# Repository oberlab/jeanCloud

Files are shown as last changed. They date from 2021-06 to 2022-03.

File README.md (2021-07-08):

<p align="center">
<h1 align="center">jeanCloud</h1>
<h3 align="center">Your personal cloud (alarm) clock</h3>
</p>

<p align="center">
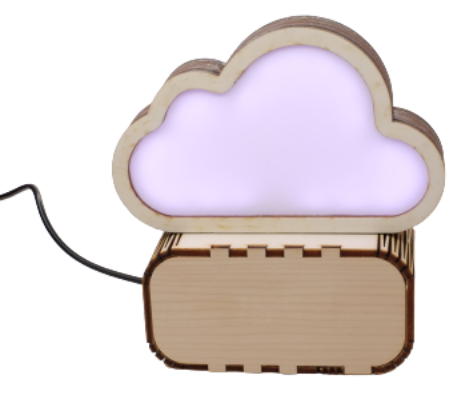
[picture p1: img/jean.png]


</p>
<br>
<br>

### How to set up your JeanCloud in your home network

1. Connect your JeanCloud to power
2. Wait until the JeanCloud WiFi appears
3. Connect to the JeanCloud WiFi and enter 192.168.4.1 into your web browser (NO GOOGLE SEARCH)
4. You should see a web interface in which you can enter the name and password of your home WiFi
5. After you press "save" the JeanCloud WiFi should disappear and your JeanCloud connects to your home WiFi
6. You can access the web interface of your JeanCloud by entering its IP address into your web browser (with a device which is in the SAME network). You can identify the IP address of your JeanCloud either by using any network analysis tool (like the [app fing](https://www.fing.com/products/fing-app)) or looking into your router web interface. Check for connected (generic) devices and identify your JeanCloud (sometimes the device is named "espressif")

### Jean Cloud mit dem Heimnetzwerk verbinden

1. Versorge deinen JeanCloud mit Strom
2. Warte bis das JeanCloud WLan erscheint
3. Verbinde dich mit dem JeanCloud WLan und gebe 192.168.4.1 in der Adresszeile deines Webbrowsers ein (KEINE GOOGLE SUCHE)
4. Du solltest jetzt ein Webinterface sehen in dem du den Namen und das Passwort deines Heimnetzwerks eingeben kannst
5. Wenn du jetzt "Speichern" drückst, sollte das JeanCloud WLan verschwinden und dein JeanCloud sich mit deinem Heimnetzwerk verbinden
6. Du kannst jetzt das Webinterface zur Steuerung des Lichts etc. aufrufen indem du die IP Adresse deines JeanClouds in der Adresszeile deines Webbrowsers eingibst. Du kannst die IP Adresse deines JeanClouds entweder durch ein Netzwerkanalyse Tool wie z.B. die [App fing](https://www.fing.com/products/fing-app) oder über das Webinteface von deinem Heimrouter (schau unter verbundene Geräte) herausfinden.

### Electronic connections

**Display:** CLK to pin 18, DIO to pin 5, 5V to 3V3, GND to GND
**LED-Strip:** Data to pin 14, 5V to 5V or Vin, GND to GND
**Buzzer:** one leg to pin 32, one leg to GND (use the one of the display)

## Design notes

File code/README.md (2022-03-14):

## Pin Usage
**Display:** CLK to pin 18, DIO to pin 5
**LED-Strip:** pin 14
**Buzzer:** pin 32

## Inspiration:

- [show text in with the 4-digit display](https://www.rahner-edu.de/mikrocontroller/seeeduino-nano/4-digit-display/)
- [different WS2811 LED pattern (FastLED)](https://www.tweaking4all.com/hardware/arduino/arduino-all-ledstrip-effects-in-one/)

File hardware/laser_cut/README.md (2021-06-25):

## Files for lasercutting

## How to create your own cloud design
I suggest to use [Inkscape](https://inkscape.org/) to create your own cloud design. Follow these steps:

(Use an area of about 140 x 80 mm for your drawing)

1. Draw circles or ellipses. The outer shape will form the outline of your cloud
<p align="center">
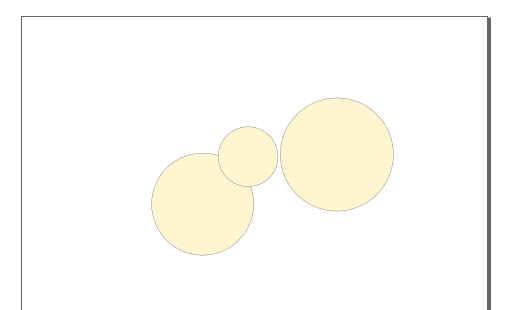
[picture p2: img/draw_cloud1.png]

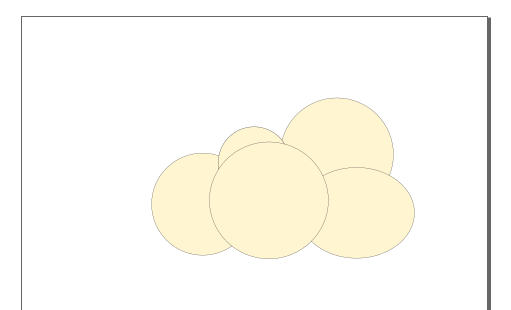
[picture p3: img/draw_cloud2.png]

</p>

2. Select all circles and unionize them to one shape (Path > Union or press ctrl and +)

<p align="center">
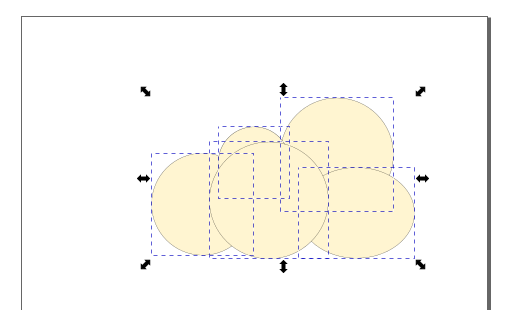
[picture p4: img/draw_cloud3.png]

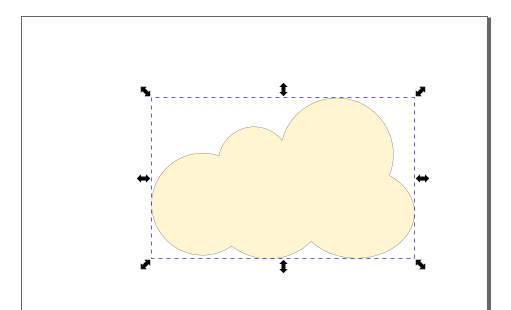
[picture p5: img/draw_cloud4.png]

</p>

3. Duplicate the shape (ctrl + D or right click on the shape) two times. Put one to the side for later. Create an dynamic offset with the other duplicate (Path > Dynamic offset or press ctrl + J). Pull the dynamic offset in any direction.

<p align="center">
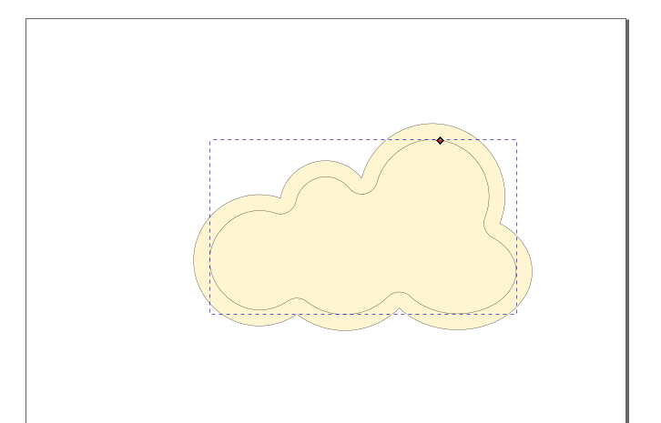
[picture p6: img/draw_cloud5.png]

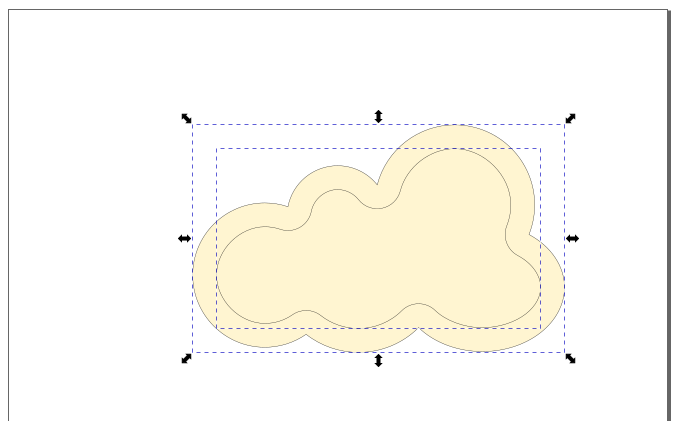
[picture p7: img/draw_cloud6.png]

</p>

4. First duplicate the offset shape (ctrl + D or right click on the shape) and put it to the side  Now subtract (Path > Difference or ctrl + -) the new smaller shape from the previous one. Again create a duplicate (ctrl + D or right click on the shape) and put it to the side for later.

<p align="center">
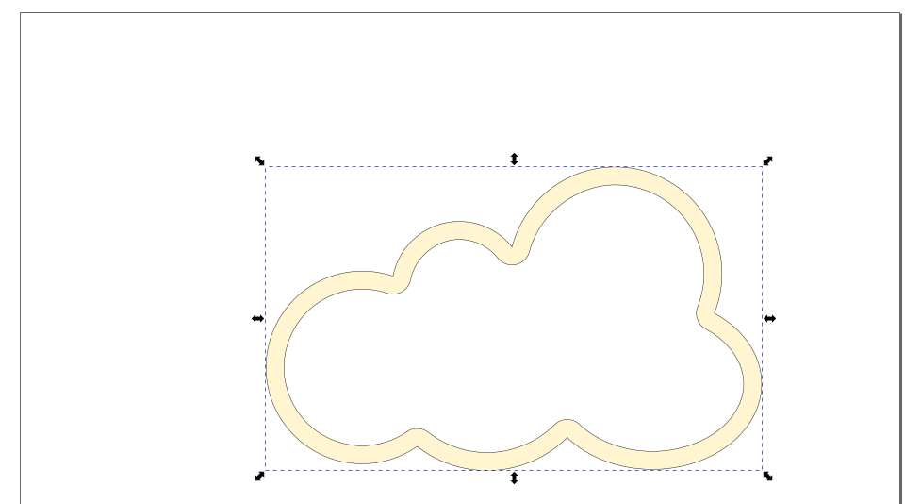
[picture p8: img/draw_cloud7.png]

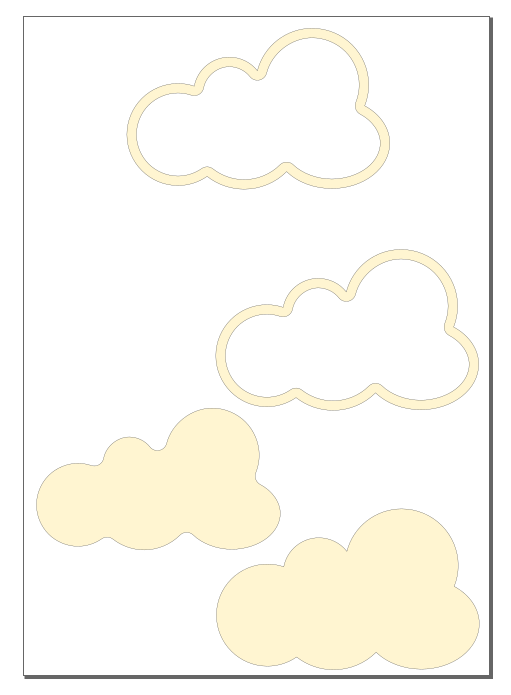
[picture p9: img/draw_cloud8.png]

</p>

5. Create a rectangle with 70 mm width and 25 mm height and place it below the cloud. Unionize both shapes (Path > Union or press ctrl and +). This is the part you will insert into the box later.

<p align="center">
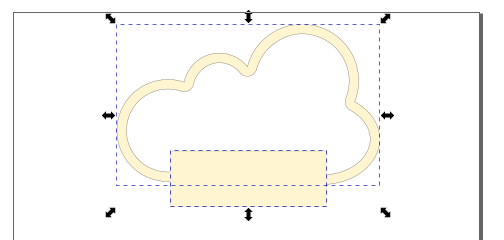
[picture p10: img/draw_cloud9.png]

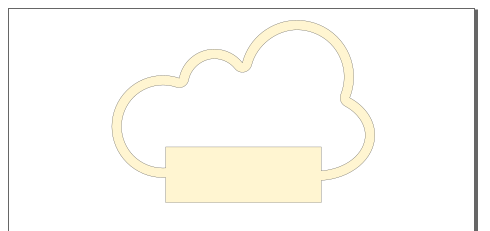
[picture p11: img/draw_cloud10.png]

</p>

6. Create a a duplicate of the offset shape (from step 4) and put it into the cloud shape with the box. Subtract it from the shape (Path > Difference or ctrl + -) to get a nice inner shape again (there are better ways to do this but this one seemed easier for me).

<p align="center">
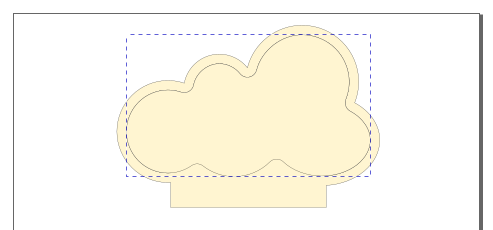
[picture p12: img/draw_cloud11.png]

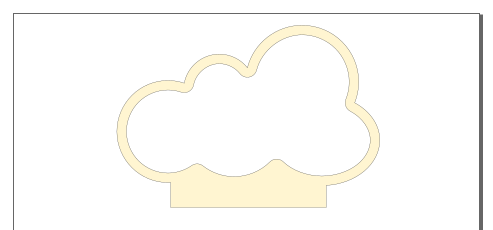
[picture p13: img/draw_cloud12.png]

</p>

7. Now we need to create a channel for the LED cables. Create a small rectangle with 15 mm width (height does not matter) and place it in the middle of the bottom part and subtract it from the shape (Path > Difference or ctrl + -).

<p align="center">
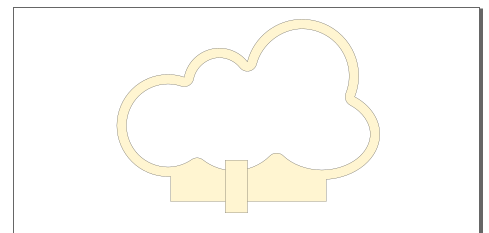
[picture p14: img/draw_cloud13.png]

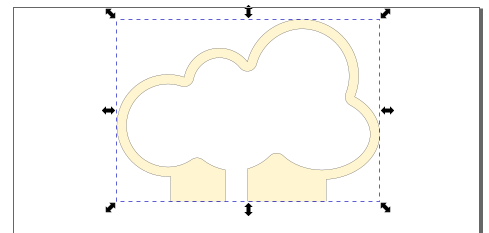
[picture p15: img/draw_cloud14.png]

</p>

8. Quick check. You should now have 4 shapes on your inkscape document: 1. Outline with connector and cable channel (from step 7), 2. Outline (from step 4), 3. Offset cloud shape (from step 4) and 4. Cloud shape (from step 2).

<p align="center">
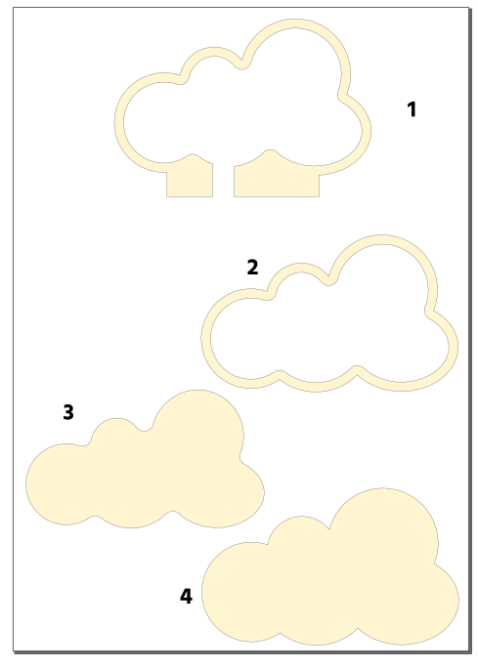
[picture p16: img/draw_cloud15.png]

</p>

9. Now let's create the parts which hold the veneer/white sheet for the light. Duplicate the outline shape created in step 4 (number in the previous picture) and drag it to the side. Lay the cloud shape over the duplicated outline.

<p align="center">
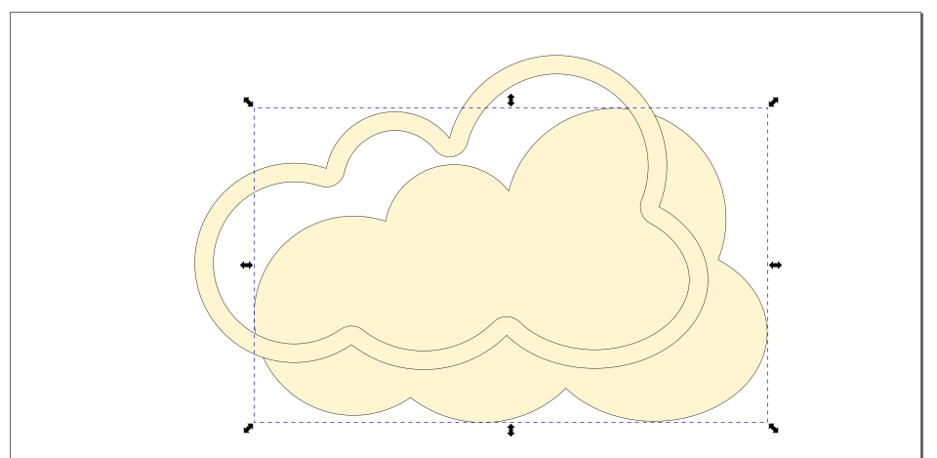
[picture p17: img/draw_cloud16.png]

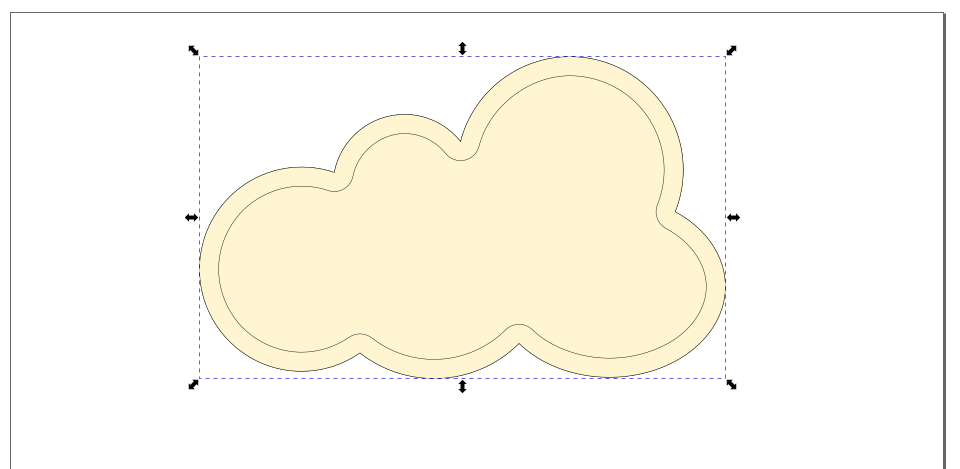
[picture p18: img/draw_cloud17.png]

</p>

10. Select the cloud shape and do a dynamic offset again (Path > Dynamic offset or press ctrl + J) and pull it in the middle of the Cloud Outline. You might have to zoom in to get it right.

<p align="center">
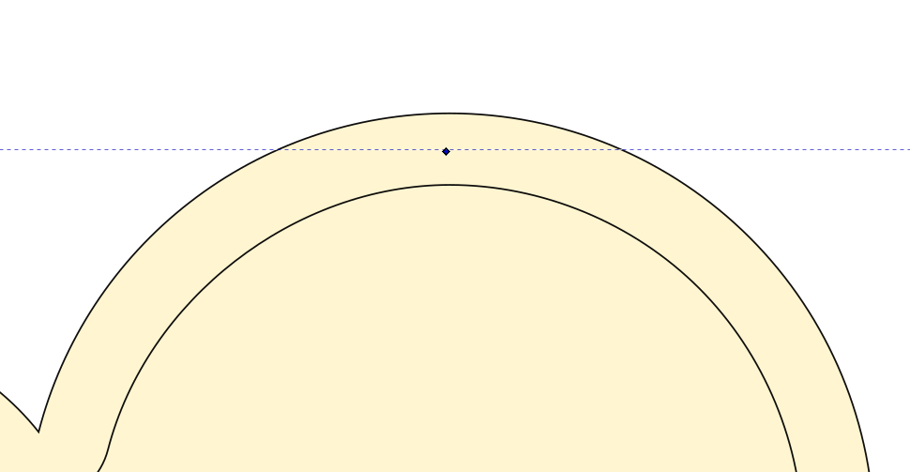
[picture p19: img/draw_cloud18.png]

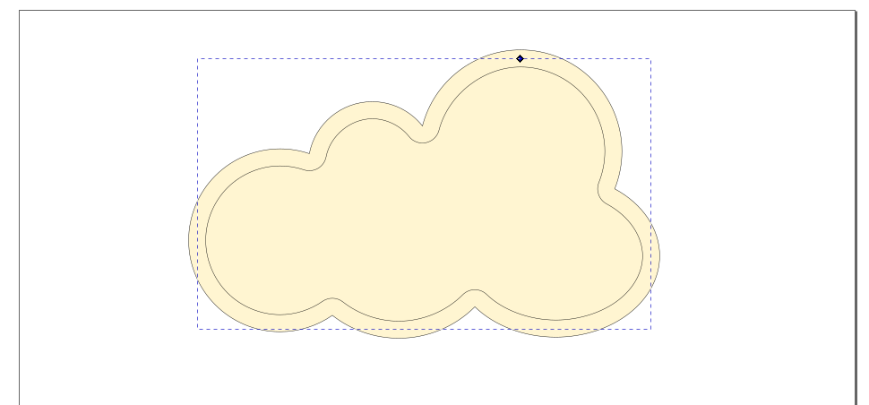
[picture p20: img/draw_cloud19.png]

</p>

11. Create a duplicate of the new shape and put it to the side. Now select both overlaying shapes and create an intersection (Path > Intersection or ctrl + *)

<p align="center">
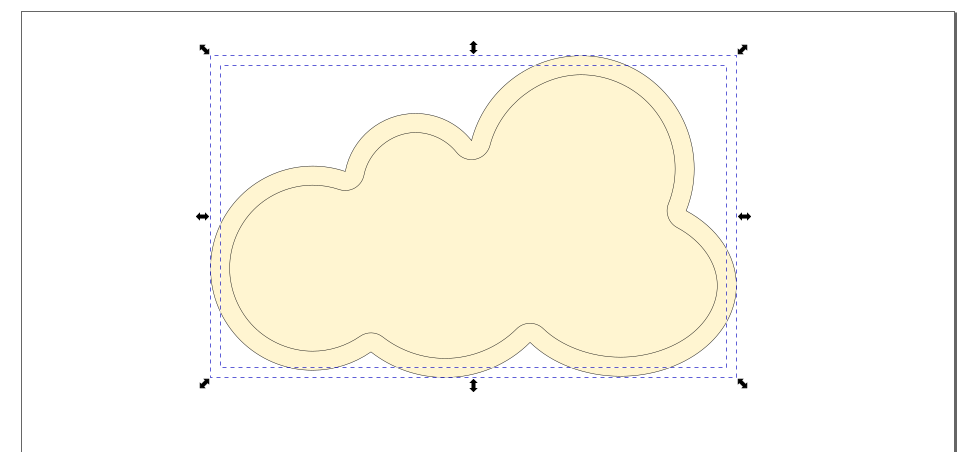
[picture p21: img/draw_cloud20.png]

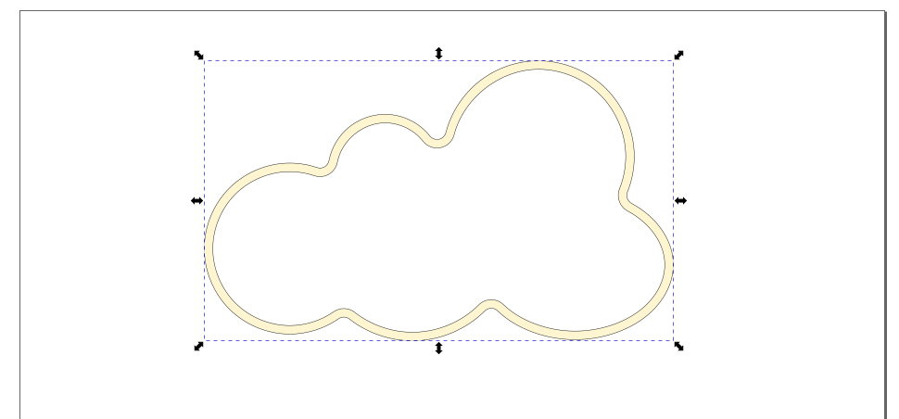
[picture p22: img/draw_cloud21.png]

</p>

12. For the last part create a duplicate of the cloud outline again and a duplicate from the smaller cloud shape we created in step 10/11. Drag them both to the side and lay them over each other. It is important that the bigger shape is below the smaller shape. You can change the order in the toolbar. They should be also perfectly centred to each other. You can do this by using the Align and Distribute tool (Object > Align and Distribute)  Finally subtract the shapes (Path > Difference or ctrl + -).

<p align="center">
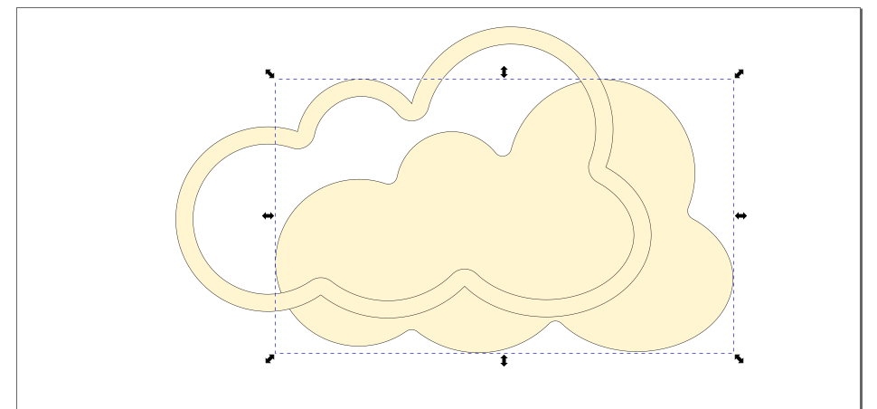
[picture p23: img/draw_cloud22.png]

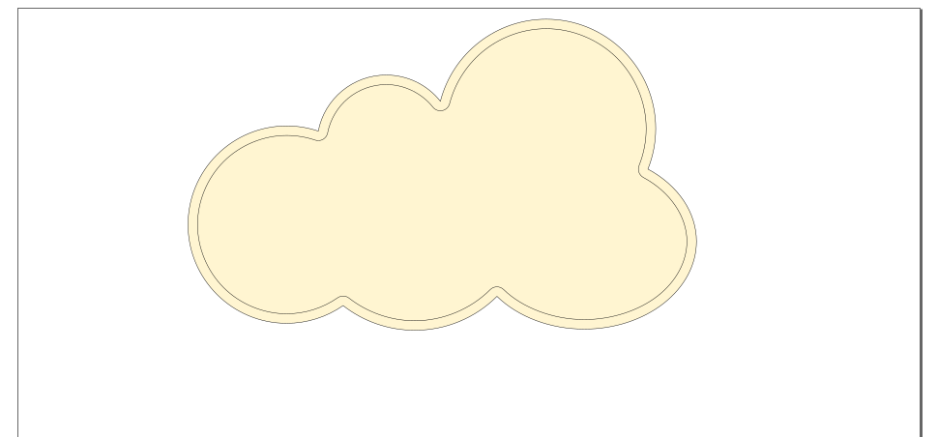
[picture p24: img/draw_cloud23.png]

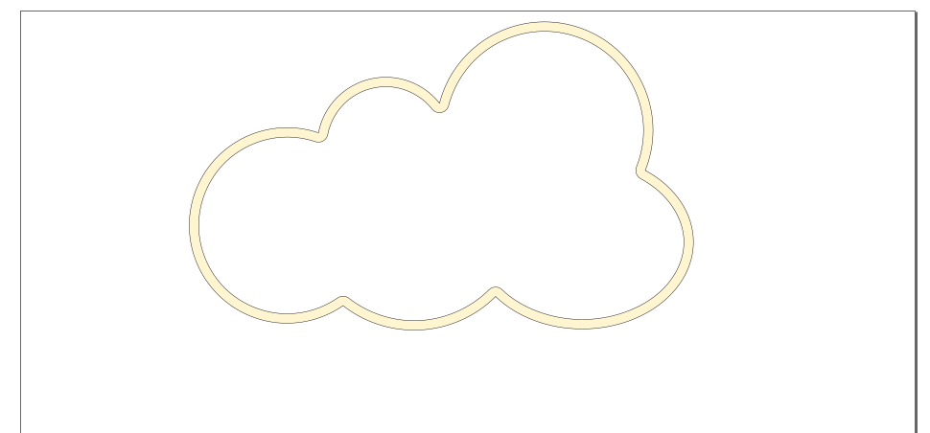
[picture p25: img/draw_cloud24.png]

</p>

13. Final check! Now you should have 5 shapes! 1. The outer outline (from step 12), the cloud outline, 3. the inner outline (from step 11), 4. outline with connector and cable channel (from step 7) and 5. smaller cloud shape from step 11.

<p align="center">

</p>

### Box generators
- [MakerCase](https://de.makercase.com/)
- [boxes.py](https://www.festi.info/boxes.py/)

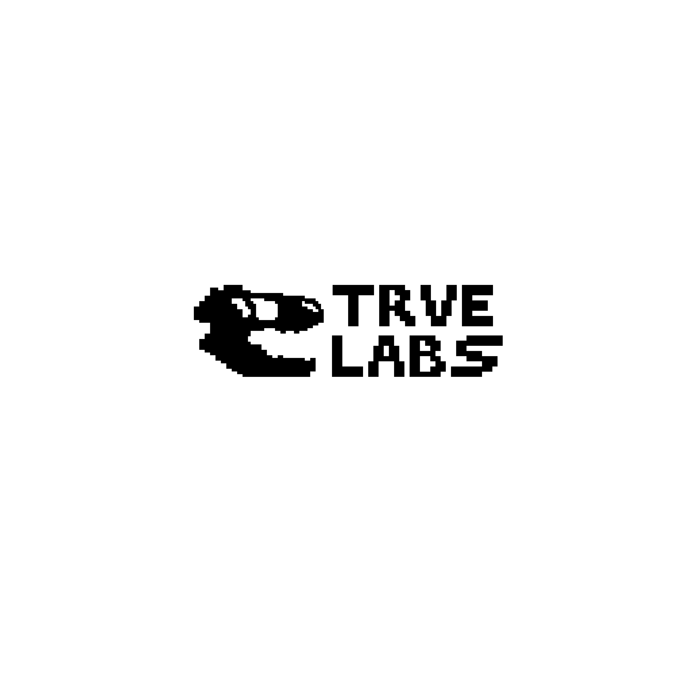
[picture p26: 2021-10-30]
hardware/pcb/regular/.svg2shenzhen-cache/images/F.Mask_g844.png

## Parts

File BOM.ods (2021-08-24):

Quantity | Description | Where to buy? | Example | Aprox. Costs per unit | Aprox. Costs (per JeanCloud) | Total est. costs
1 | ESP32 Dev Kit | anywhere | Aliexpress (https://de.aliexpress.com/item/32807887667.html) | 5.00 € | 2.00 € | 23.50 €
1 | active Buzzer | anywhere | digikey (https://www.digikey.de/product-detail/de/tdk-corporation/PS1240P02BT/445-2525-1-ND/935930) | 0.50 € | 0.50 €
1 | 4-digits TM1637 Display | anywhere | Aliexpress (https://de.aliexpress.com/item/32838969764.html) | 2.50 € | 2.50 €
1 | WS2812B LED Strip (NeoPixel) | anywhere | Aliexpress (https://de.aliexpress.com/item/32832420003.html) | 2.00 € | 2.00 €
1 | connector cables | anywhere | Aliexpress (https://de.aliexpress.com/item/4000203371860.html) | 2.00 € | 2.00 €
2 | PCB Push Buttons | anywhere | Aliexpress (https://de.aliexpress.com/item/4000113193157.html) | 0.50 € | 1.00 €
1 | MicroUSB Adapter (optional) | anywhere | Amazon (https://www.amazon.de/gp/product/B0754MNQPN?psc=1) | 7.00 € | 7.00 €
1 | Wood housing | Laser cut | - | 5.00 € | 5.00 €
1 | CloudPush Adapter | 3D-print | - | 1.00 € | 1.00 €
1 | DisplaySpacer | 3D-print | - | 0.50 € | 0.50 €

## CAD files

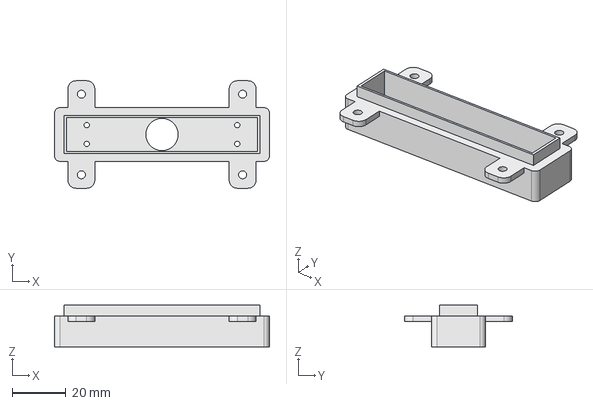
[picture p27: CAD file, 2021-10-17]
hardware/3D_print/CloudPush/CloudPush.FCStd
80.0 x 40.0 x 15.5 mm

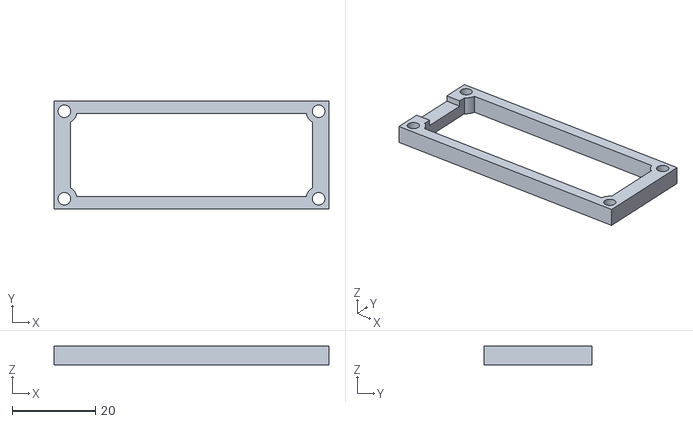
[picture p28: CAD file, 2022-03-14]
hardware/3D_print/DisplaySpace/DisplaySpacer-Body.obj
66.0 x 26.0 x 4.50

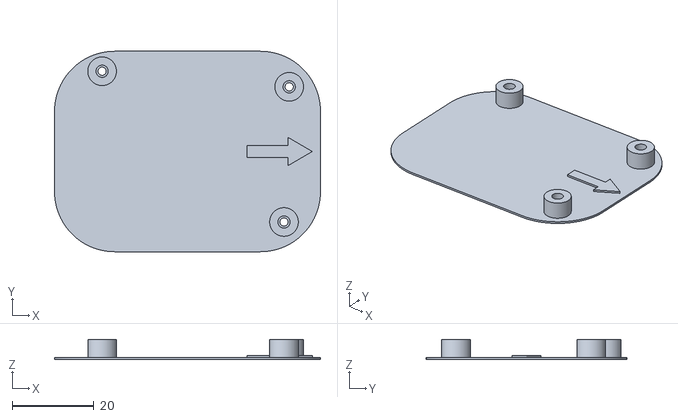
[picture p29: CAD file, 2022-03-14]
hardware/3D_print/PCBholder/PCBholder-Body.obj
65.0 x 49.0 x 5.00

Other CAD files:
hardware/3D_print/CloudPush/CloudPush-Body.obj
hardware/3D_print/DisplaySpace/DisplaySpacer.FCStd
hardware/3D_print/PCBholder/PCBholder.FCStd

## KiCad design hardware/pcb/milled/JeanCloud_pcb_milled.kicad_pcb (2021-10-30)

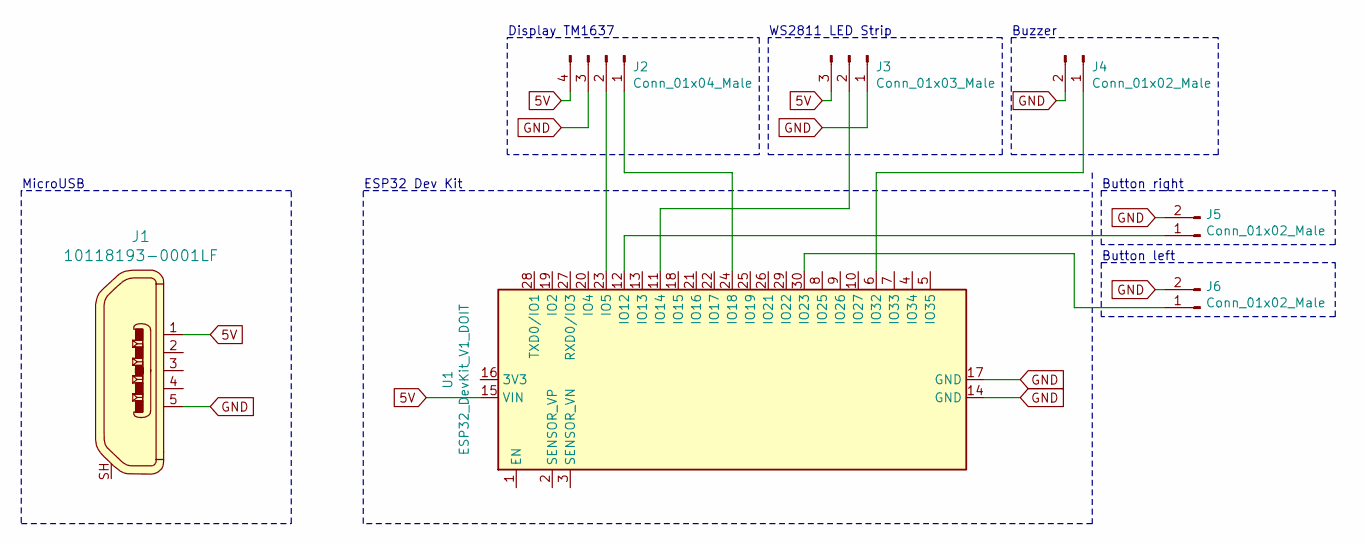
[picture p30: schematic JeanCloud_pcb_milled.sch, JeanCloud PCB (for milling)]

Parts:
J1: 10118193-0001LF; USB_Micro_B_Female_10118193-0001LF; MPN 10118193-0001LF; Digi-Key_PN 609-4616-1-ND
J2: Conn_01x04_Male; PinHeader_1x04_P2.54mm_Vertical
J3: Conn_01x03_Male; PinHeader_1x03_P2.54mm_Vertical
J4, J5, J6: Conn_01x02_Male; PinHeader_1x02_P2.54mm_Vertical
U1: ESP32_DevKit_V1_DOIT; esp32_devkit_v1_doit

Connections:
5V: J1.1, J2.4, J3.3, U1.15 (VIN)
GND: J1.5, J2.3, J3.1, J4.2, J5.2, J6.2, U1.14 (GND), U1.17 (GND)
unnamed: J2.1, U1.24 (IO18)
unnamed: J2.2, U1.23 (IO5)
unnamed: J3.2, U1.11 (IO14)
unnamed: J4.1, U1.6 (IO32)
unnamed: J5.1, U1.12 (IO12)
unnamed: J6.1, U1.30 (IO23)

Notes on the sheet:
Display TM1637
WS2811 LED Strip
Buzzer
Button right
Button left
ESP32 Dev Kit
MicroUSB

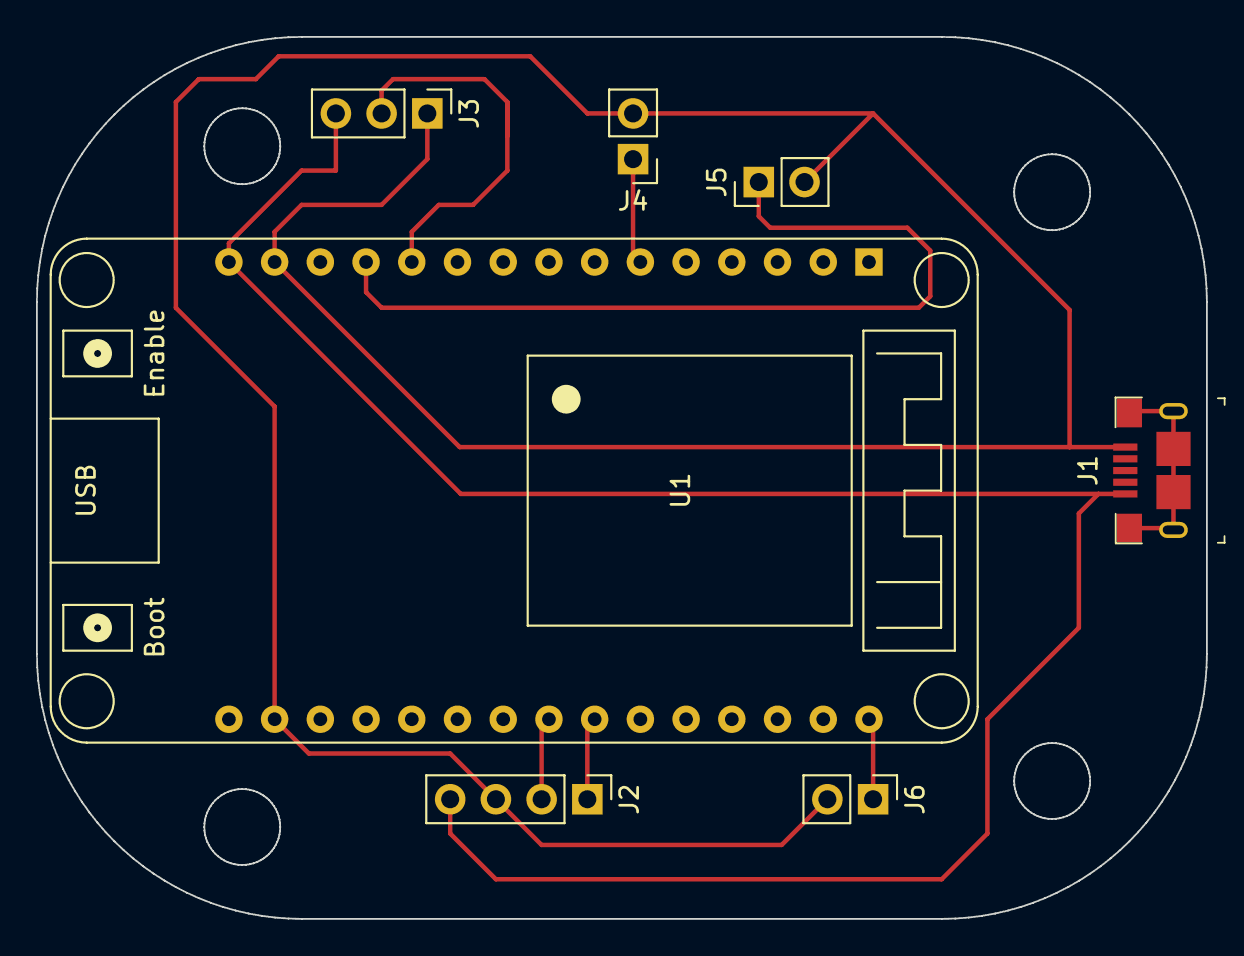
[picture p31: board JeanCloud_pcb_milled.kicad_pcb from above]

Board: 2 copper layers, 65.0 x 49.0 mm, 7 parts (0 on the bottom side), 8 nets.

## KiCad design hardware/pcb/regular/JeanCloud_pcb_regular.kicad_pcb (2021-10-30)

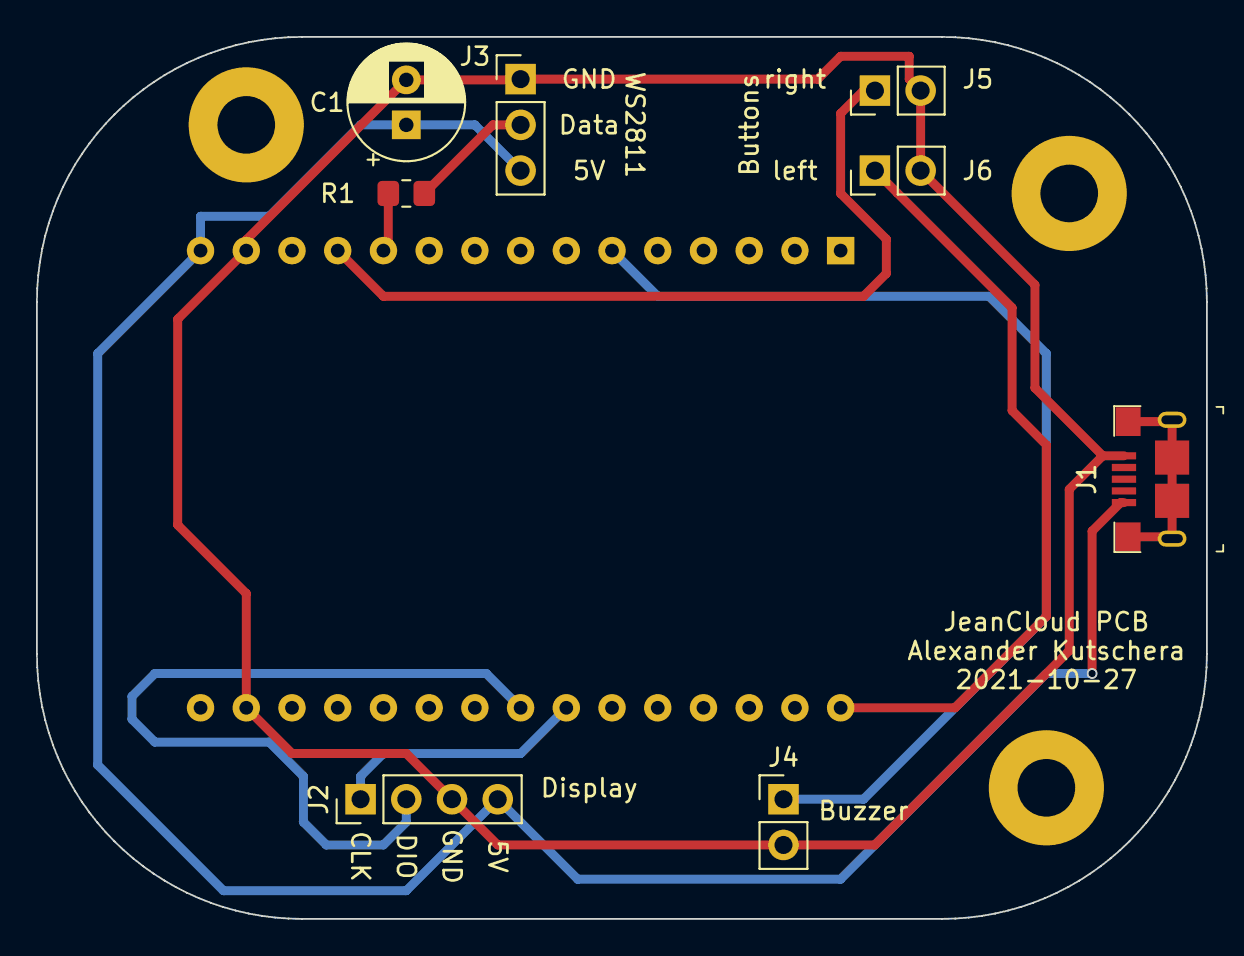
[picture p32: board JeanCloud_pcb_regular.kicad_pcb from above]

Board: 2 copper layers, 65.0 x 49.0 mm, 12 parts (0 on the bottom side), 9 nets.

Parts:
 : MountingHole_3.2mm_M3_Pad
 #2,  #3: MountingHole_3.2mm_M3_Pad
 #4: ESP32_DevKit_V1_DOIT; esp32_devkit_v1_doit
C1: CP; CP_Radial_D6.3mm_P2.50mm
J1: 10118193-0001LF; USB_Micro_B_Female_10118193-0001LF
J2: Conn_01x04_Male; PinHeader_1x04_P2.54mm_Vertical
J3: Conn_01x03_Male; PinHeader_1x03_P2.54mm_Vertical
J4, J5, J6: Conn_01x02_Male; PinHeader_1x02_P2.54mm_Vertical
R1: R; R_0805_2012Metric_Pad1.20x1.40mm_HandSolder

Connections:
5V: #4.15, C1.1, J1.1, J2.4, J3.3
GND: #4.14, #4.17, C1.2, J1.5, J2.3, J3.1, J4.2, J5.2, J6.2
unnamed: #4.24, J2.1
unnamed: #4.23, J2.2
unnamed: J3.2, R1.1
unnamed: #4.6, J4.1
unnamed: #4.12, J5.1
unnamed: #4.30, J6.1
unnamed: #4.11, R1.2

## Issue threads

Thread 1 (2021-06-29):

feature list v1

vektorious, 2021-06-29:
- [x] Webserver
- [x] get time (sync.
- [x] switch light on/off (Backend)
- [x] switch light on/off (Frontend)
- [x] set color (R, G, B)
- [x] Show Status (Intestity)
- [x] AP if no WiFi connection
- [x] set alarm time
- [x] switch alarm on and off

---
*optional*
- [ ] set alarm melody
- [ ] LED pattern/light modes

---
*super optional*
- [ ] connect to open weather map and show the weather

vektorious, 2021-07-09:
Closed because we are changing our project management

Closed 2021-07-09.

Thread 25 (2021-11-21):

winter/summer time switch

vektorious, 2021-11-21:
Switch between German winter and summer time is not working. Needs to be fixed.
Maybe check date at startup and adjust offset accordingly.

vektorious, 2022-03-11:
@konstantinullrich

Closed 2022-03-17.

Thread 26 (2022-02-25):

Add watchdog reset

vektorious, 2022-02-25:
https://iotespresso.com/create-custom-watchdog-timer-in-esp32/

vektorious, 2022-02-25:
https://iotespresso.com/create-custom-watchdog-timer-in-esp32/

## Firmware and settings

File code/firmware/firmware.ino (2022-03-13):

#include <AsyncTCP.h>
#include <ESPAsyncWebServer.h>
#include <ESPmDNS.h>
#include <FastLED.h>
#include <SPIFFS.h>
#include <TM1637Display.h>
#include <WiFi.h>
#include <time.h>
#include "./src/hardware/LightController.h"
#include "./src/network/MDNSController.h"
#include "./src/AlarmController.h"
#include "./src/PasswordController.h"
#include "./src/hardware/System.h"
#include "./src/Webserver.h"

char *name = "Konsti's JeanCloud";
char *hostname = "jeancloud";
char *passwort = "passwort123";

// Define the connections pins for display:
#define CLK 18
#define DIO 5

// Create display object:
TM1637Display display = TM1637Display(CLK, DIO);

// time settings
#define MY_NTP_SERVER "de.pool.ntp.org"  
#define MY_TZ "CET-1CEST,M3.5.0/02,M10.5.0/03" // https://github.com/nayarsystems/posix_tz_db/blob/master/zones.csv


MDNSController mdnsController = MDNSController(hostname, name);
LightController lightController = LightController();
AlarmController alarmController = AlarmController(&lightController);
Webserver webserver = Webserver(80, lightController, &alarmController, &display);
Webserver apWebserver = Webserver(80, lightController, &alarmController, &display);

bool isSetup = false;

struct Button
{
  uint8_t pin;
  uint32_t numberKeyPresses;
  bool pressed;
};

Button buttonRight = {12, 0, false};
Button buttonLeft = {33, 0, false};

void IRAM_ATTR buttonRightIRS()
{
  buttonRight.numberKeyPresses += 1;
  buttonRight.pressed = true;
}

void IRAM_ATTR buttonLeftIRS()
{
  buttonLeft.numberKeyPresses += 1;
  buttonLeft.pressed = true;
}

void setup()
{
  Serial.begin(115200);

  // setup display
  display.setBrightness(7); // Set the display brightness (0-7)
  display.clear();          // Clear the display

  System::initFS();

  PasswordController passwordController = PasswordController("/wifi.txt");

  pinMode(buttonRight.pin, INPUT_PULLUP);
  pinMode(buttonLeft.pin, INPUT_PULLUP);
  attachInterrupt(buttonRight.pin, buttonRightIRS, FALLING);
  attachInterrupt(buttonLeft.pin, buttonLeftIRS, FALLING);

  if (!passwordController.isExisting())
  {
    isSetup = true;
  }
  else
  {
    isSetup = !System::connectToWifi(&passwordController);
  }

  if (isSetup)
  {
    WiFi.disconnect();
    WiFi.mode(WIFI_AP);
    WiFi.softAP(name, passwort);

    mdnsController.setup();

    apWebserver.setupAP();
    apWebserver.begin();
    Serial.println(WiFi.softAPIP());
  }

  if (isSetup)
  {
    return;
  }

  // Setup jeancloud.local domain for local network
  mdnsController.setup();

  // Print ESP Local IP Address
  Serial.println(WiFi.localIP());

  // Init and get the time
  configTzTime(MY_TZ, MY_NTP_SERVER);

  struct tm timeinfo;

  if (!getLocalTime(&timeinfo))
  {
    Serial.println("Failed to obtain time");
    display.showNumberDec(0);
    return;
  }

  char timeHour[3];
  strftime(timeHour, 3, "%H", &timeinfo);
  char timeMinute[3];
  strftime(timeMinute, 3, "%M", &timeinfo);

  int displayTime = atoi(timeHour) * 100 + atoi(timeMinute);
  Serial.println(displayTime);
  display.showNumberDecEx(displayTime, 0b11100000, true); //Display the time value;

  webserver.setup();
  webserver.begin();
}

void loop()
{

  // Don't Execute anything if it is setting up
  if (isSetup)
  {
    lightController.bounce();
    return;
  }

  EVERY_N_MILLIS(600)
  {
    if (buttonRight.pressed && buttonLeft.pressed)
    {
      alarmController.stopAlarm();
    }
    else
    {
      if (buttonRight.pressed)
      {
        alarmController.snooze();
        buttonRight.pressed = false;
      }

      if (buttonLeft.pressed)
      {
        alarmController.snooze();
        buttonLeft.pressed = false;
      }
    }
  }

  // put your main code here, to run repeatedly:
  EVERY_N_MILLIS(200)
  {
    struct tm timeinfo;
    if (!getLocalTime(&timeinfo))
    {
      Serial.println("Failed to obtain time");
      display.showNumberDec(0);
      return;
    }
    Serial.println(&timeinfo, "%A, %B %d %Y %H:%M:%S");

    char timeHour[3];
    strftime(timeHour, 3, "%H", &timeinfo);
    char timeMinute[3];
    strftime(timeMinute, 3, "%M", &timeinfo);
    int displayTime = atoi(timeHour) * 100 + atoi(timeMinute);
    display.showNumberDecEx(displayTime, 0b11100000, true); //Display the time value;
    alarmController.loop(atoi(timeHour), atoi(timeMinute));
  }
}

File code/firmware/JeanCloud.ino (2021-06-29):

#include "LightController.h"
#include "Webserver.h"
#include <FastLED.h>
#include <WiFi.h>


const char* ssid = "ALK_mobil";
const char* password = "urlaubingseng20";

// fastLED configuration:
#define NUM_LEDS 27        // set number of LEDs here
#define LED_PIN 14
#define LED_TYPE WS2811
#define COLOR_ORDER GRB
CRGB leds[NUM_LEDS]; // Define the array of ledsw

LightController lightController = LightController();
Webserver webserver = Webserver();

void setup() {
    Serial.begin(115200);

    // Connect to Wi-Fi
    WiFi.begin(ssid, password);
    while (WiFi.status() != WL_CONNECTED) {
      delay(1000);
      Serial.println("Connecting to WiFi..");
    }

    // Print ESP Local IP Address
    Serial.println(WiFi.localIP());

    FastLED.addLeds<LED_TYPE, LED_PIN, COLOR_ORDER>(leds, NUM_LEDS).setCorrection( TypicalLEDStrip );
    fill_solid( leds, NUM_LEDS, CRGB(lightController.getRed(), lightController.getGreen(), lightController.getBlue()));
    FastLED.setBrightness(sliderValue.toInt());
    FastLED.show();

    webserver.setup();
    webserver.begin();
}

void loop() {
  // put your main code here, to run repeatedly:

}

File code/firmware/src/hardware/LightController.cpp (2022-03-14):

#include <Arduino.h>
#include <FastLED.h>
#include "LightController.h"

// fastLED configuration:
#define NUM_LEDS 15 // set number of LEDs here
#define LED_PIN 14
#define LED_TYPE WS2811
#define COLOR_ORDER GRB
CRGB leds[NUM_LEDS]; // Define the array of ledsw

int x = 0;
bool up = true;

LightController::LightController()
{
  red = 255;
  blue = 255;
  green = 255;
  intensity = 255;
  FastLED.addLeds<LED_TYPE, LED_PIN, COLOR_ORDER>(leds, NUM_LEDS).setCorrection(TypicalLEDStrip);
  fill_solid(leds, NUM_LEDS, CRGB(255, 255, 255));
}

void LightController::on()
{
  FastLED.setBrightness(intensity);
  FastLED.show();
}

void LightController::off()
{
  FastLED.setBrightness(0);
  FastLED.show();
}

void LightController::setRGB(int _red, int _green, int _blue)
{
  red = _red;
  green = _green;
  blue = _blue;
  fill_solid(leds, NUM_LEDS, CRGB(red, green, blue));
}

void LightController::setIntenstiy(int _intensity)
{
  intensity = _intensity;
}

void LightController::bounce()
{
  EVERY_N_MILLIS(50)
  {
    Serial.println(x);
    fill_solid(leds, NUM_LEDS, CRGB(0, 0, 0));
    leds[x] = CRGB(255, 255, 255);
    leds[x + 1] = CRGB(255, 255, 255);
    leds[x + 2] = CRGB(255, 255, 255);
    FastLED.show();

    if (x < NUM_LEDS - 3 && up)
    {
      x++;
    }
    else if (x == NUM_LEDS - 3 && up)
    {
      up = false;
      x--;
    }
    else if (x == 0 && !up)
    {
      up = true;
    }
    else
    {
      x--;
    }
  }
}

void LightController::runner()
{
  EVERY_N_MILLIS(100)
  {
    Serial.print(x);
    fill_solid(leds, NUM_LEDS, CRGB(0, 0, 0));
    leds[x] = CRGB(255, 255, 255);
    if (x > 0)
    {
      leds[x - 1] = CRGB(255, 255, 255);
      Serial.print(x) - 1;
    }
    else
    {
      leds[NUM_LEDS - 2] = CRGB(255, 255, 255);
    }

    if (x > 1)
    {
      leds[x - 2] = CRGB(255, 255, 255);
      Serial.println(x - 2);
    }
    else
    {
      leds[NUM_LEDS - 1] = CRGB(255, 255, 255);
      Serial.print(NUM_LEDS - 1);
    }

    FastLED.show();

    if (x < NUM_LEDS)
    {
      x++;
    }
    else
    {
      x = 0;
    }
  }
}

void LightController::pulse()
{

  EVERY_N_MILLIS(10)
  {

    FastLED.setBrightness(x);

    if (x < 255 && up)
    {
      x++;
    }
    else if (x == 255 && up)
    {
      up = false;
      x--;
    }
    else if (x == 0 && !up)
    {
      up = true;
    }
    else
    {
      x--;
    }
    FastLED.show();
  }
}

void LightController::flash_white()
{
  fill_solid(leds, NUM_LEDS, CRGB(255, 255, 255));

  EVERY_N_MILLIS(500)
  {
    FastLED.setBrightness(255);
    FastLED.show();
  }

  EVERY_N_MILLIS(300)
  {
    FastLED.setBrightness(0);
    FastLED.show();
  }
}

void LightController::setPattern() {}

int LightController::getIntenstiy() { return intensity; }

int LightController::getRed() { return red; }

int LightController::getGreen() { return green; }

int LightController::getBlue() { return blue; }

bool LightController::isActive() { return FastLED.getBrightness() > 0; }

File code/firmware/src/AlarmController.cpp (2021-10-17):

#include <Arduino.h>
#include "AlarmController.h"

// Define the pin for the buzzer and configurate it:
#define BUZ 32
int freq = 2000;
int channel = 0;
int resolution = 8;

AlarmController::AlarmController(LightController *_lightController)
{
    lightController = _lightController;
    alarmHour = 8;
    alarmMinute = 0;
    alarmStatus = true;
    snoozeMinute = 5;

    // setup buzzer
    ledcSetup(channel, freq, resolution);
    ledcAttachPin(BUZ, channel);
}

void AlarmController::on()
{
    alarmStatus = true;
}

void AlarmController::off()
{
    alarmStatus = false;
}

void AlarmController::setAlarm(int hour, int minute)
{
    alarmHour = hour;
    alarmMinute = minute;
}

void AlarmController::makeNoise()
{
    ledcWrite(channel, 150);
    ledcWriteTone(channel, 4000);
    delay(100);
    ledcWriteTone(channel, 0);
    delay(500);
    ledcWriteTone(channel, 4000);
    delay(100);
    ledcWriteTone(channel, 0);
}

void AlarmController::snooze()
{
    if (beeping)
    {
        beeping = false;
        snoozeCount++;
    }
}

void AlarmController::stopAlarm()
{
    if (beeping)
    {
        beeping = false;
        alarmStopped = true;
    }
}

void AlarmController::loop(int hour, int minute)
{
    if (compareAlarmMinutes(hour, minute, 0) && getAlarmStatus())
    {
        beeping = true;
        makeNoise();
        lightController->flash_white();
    }
    else
    {
        if (compareAlarmMinutes(hour, minute, 1))
        {
            snoozeCount = 0;
            alarmStopped = false;
            beeping = false;
        }
    }
}

bool AlarmController::getAlarmStatus() { return alarmStatus && !alarmStopped; }

int AlarmController::getHour() { return alarmHour; }

int AlarmController::getMinute() { return alarmMinute; }

bool AlarmController::compareAlarmMinutes(int hour, int minute, int offset)
{
    int alarmMinutes = (alarmHour * 60) + alarmMinute + (snoozeMinute * snoozeCount);
    int currentMinutes = (hour * 60) + minute;
    return (alarmMinutes + offset) == currentMinutes;
}

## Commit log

2021-06-24 uploaded hardware file (laser), added content to README
2021-06-24 added structure
    [BOM.csv]
2021-06-29 Add Arduino
2021-06-29 fixed error in webserver
    [Webserver.cpp]
2021-07-04 fixed wifi credential storage
    [PasswordController.cpp, firmware.ino]
2021-07-27 add push button thing
    [CloudPush-Body.obj, CloudPush.FCStd]
2021-08-04 Add one Button
2021-08-07 updated BOM
    [BOM.csv, BOM.ods]
2021-08-07 updated CloudPush 3D-model
    [CloudPush-Body.obj, CloudPush.FCStd]
2021-08-10 fixed weird alarm sounds
    [AlarmController.cpp]
2021-08-24 removed fade function becasue it did not work
    [LightController.cpp, firmware.ino]
2021-09-13 New Design version.
    [CloudPush-Body.obj, CloudPush.FCStd, DisplaySpacer.FCStd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]
2021-09-14 improved 3D-print
2021-09-21 Improved Display spacer, added new box type
    [DisplaySpacer-Body.obj, DisplaySpacer.FCStd]
2021-09-21 Add Buttons and Display Brightness Controll
2021-10-17 added footprints to PCB
    [JeanCloud_pcb_milled.kicad_pcb, JeanCloud_pcb_milled.sch]
2021-10-23 finished pcb for milling
    [JeanCloud_pcb_milled.kicad_pcb]
2021-10-30 finished regular PCB
    [JeanCloud_pcb_milled-B_Cu.gbr, JeanCloud_pcb_milled-Edge_Cuts.gbr, JeanCloud_pcb_milled-F_Cu.gbr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]
2022-03-14 Update hardware designs
    [DisplaySpacer-Body.obj, DisplaySpacer.FCStd, DisplaySpacer.obj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]
